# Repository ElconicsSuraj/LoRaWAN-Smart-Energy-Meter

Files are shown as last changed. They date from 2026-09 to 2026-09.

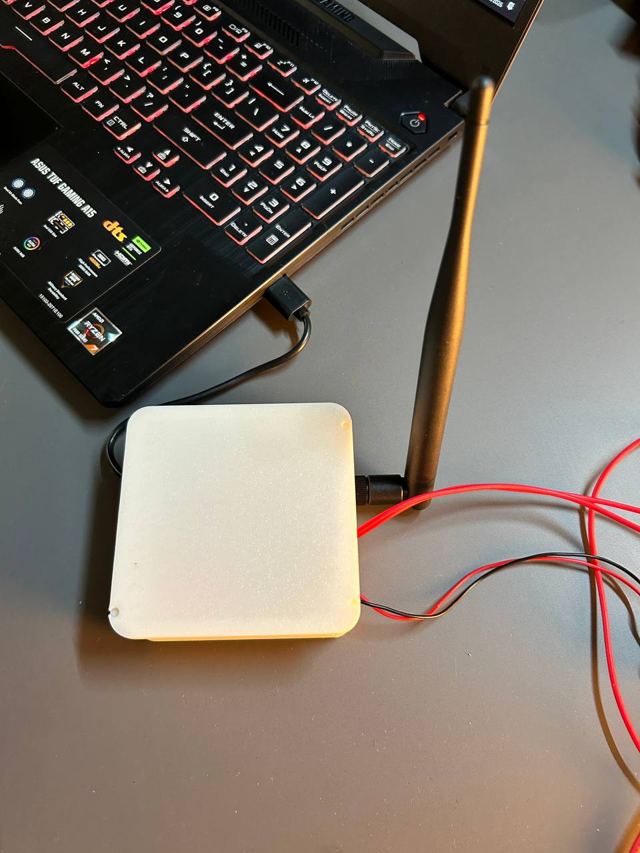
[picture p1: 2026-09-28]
Doc/images/photo_2026-09-28_18-33-33.jpg

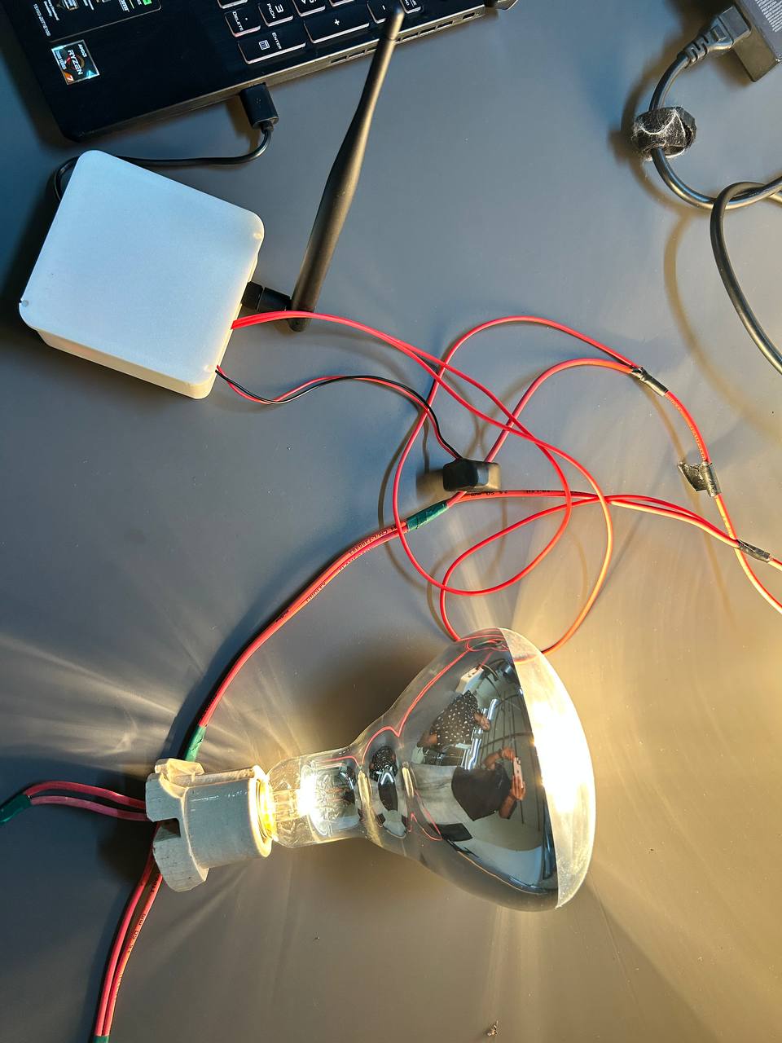
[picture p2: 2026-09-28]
Doc/images/photo_2026-09-28_18-33-32.jpg

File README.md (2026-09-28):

# LoRaWAN-Smart-Energy-Meter
A compact LoRaWAN-based energy monitoring system using the PZEM-004T V4 100A and Seeed Studio Wio-E5 Mini to remotely monitor voltage, current, power, energy consumption, power factor, and frequency.

The system uses the PZEM-004T V4 100A Energy Monitoring Module for electrical measurements and a Seeed Studio Wio-E5 Mini LoRaWAN board for long-range wireless communication.

It is suitable for applications such as industrial energy monitoring, smart buildings, agricultural equipment, commercial power monitoring, machine monitoring, and IoT-based energy management.

🚀 Features
⚡ Real-time voltage measurement
🔌 AC current measurement up to 100A
📊 Active power monitoring
🔋 Energy consumption measurement
📈 Power factor monitoring
📡 LoRaWAN long-range communication
🌐 Remote energy monitoring
🔧 Compact IoT node architecture
🔋 Suitable for low-power remote deployments
🏭 Suitable for industrial and commercial applications
🧩 Hardware Used
Component	Description
Seeed Studio Wio-E5 Mini	LoRaWAN communication controller
PZEM-004T V4 100A	AC voltage, current, power and energy measurement
100A CT	Non-invasive current measurement
Power Supply	Provides power to the monitoring node
Antenna	LoRa/LoRaWAN communication
Main Hardware

PZEM-004T V4 – 100A

Used to measure:

Voltage
Current
Active Power
Energy
Power Factor
Frequency

Wio-E5 Mini

Used as the wireless communication controller to transmit energy data over a LoRaWAN network.

🏗️ System Architecture
                 AC LOAD
                    │
                    │
             ┌──────▼──────┐
             │    100A CT  │
             └──────┬──────┘
                    │
                    ▼
          ┌───────────────────┐
          │   PZEM-004T V4    │
          │    Energy Meter   │
          │                   │
          │ V / A / W / kWh   │
          │ PF / Frequency    │
          └─────────┬─────────┘
                    │
                  UART
                    │
                    ▼
          ┌───────────────────┐
          │   Wio-E5 Mini     │
          │    LoRaWAN Node   │
          └─────────┬─────────┘
                    │
                 LoRaWAN
                    │
                    ▼
             ┌──────────────┐
             │ LoRaWAN      │
             │ Gateway      │
             └──────┬───────┘
                    │
                    ▼
             ┌──────────────┐
             │ LoRaWAN      │
             │ Network      │
             │ Server       │
             └──────┬───────┘
                    │
                    ▼
             ┌──────────────┐
             │ Dashboard /  │
             │ Cloud        │
             └──────────────┘
📡 LoRaWAN Communication

The Wio-E5 Mini communicates with a LoRaWAN gateway and transmits measured electrical parameters to the LoRaWAN network server.

Typical communication flow:

Energy Meter
     ↓
Wio-E5 Mini
     ↓
LoRaWAN
     ↓
Gateway
     ↓
LoRaWAN Network Server
     ↓
MQTT / API
     ↓
Dashboard

The device can be integrated with LoRaWAN network servers such as:

ChirpStack
The Things Stack
Other compatible LoRaWAN platforms
📊 Parameters

The device can transmit the following parameters:

Parameter	Unit
Voltage	V
Current	A
Active Power	W
Energy	kWh
Power Factor	PF
Frequency	Hz

Example payload:

{
  "voltage": 230.5,
  "current": 4.82,
  "power": 1087.4,
  "energy": 12.64,
  "power_factor": 0.98,
  "frequency": 50.0
}
🔄 Operating Flow
The PZEM-004T measures electrical parameters.
The Wio-E5 Mini communicates with the PZEM module.
Measurement data is processed by the firmware.
The data is formatted into a compact LoRaWAN payload.
The Wio-E5 Mini transmits the payload through LoRaWAN.
The LoRaWAN gateway receives the packet.
The network server processes the data.
Data can be forwarded to MQTT, database or dashboard applications.
🔌 PZEM-004T Interface

The PZEM-004T communicates with the controller using a serial interface.

Typical interface:

PZEM-004T          Wio-E5 Mini
-----------        -----------
TX      ----------> RX2
RX      <---------- TX3
GND     ----------- GND
VCC     ----------- Supply

Important: Verify the voltage levels and exact pin configuration of your PZEM-004T and Wio-E5 Mini hardware before connecting them.

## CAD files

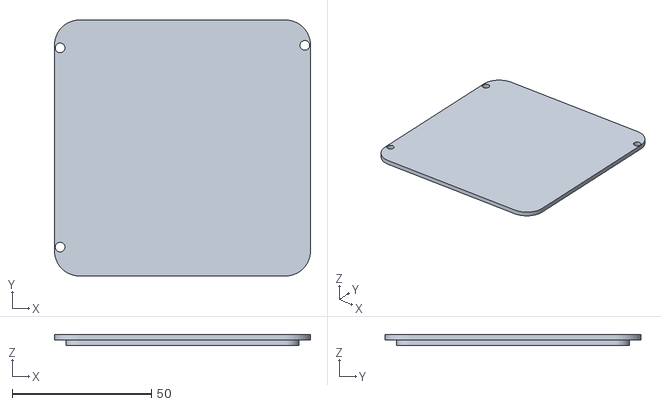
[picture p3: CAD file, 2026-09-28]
cad_file/main_box_lid.stl
92.0 x 92.0 x 4.00

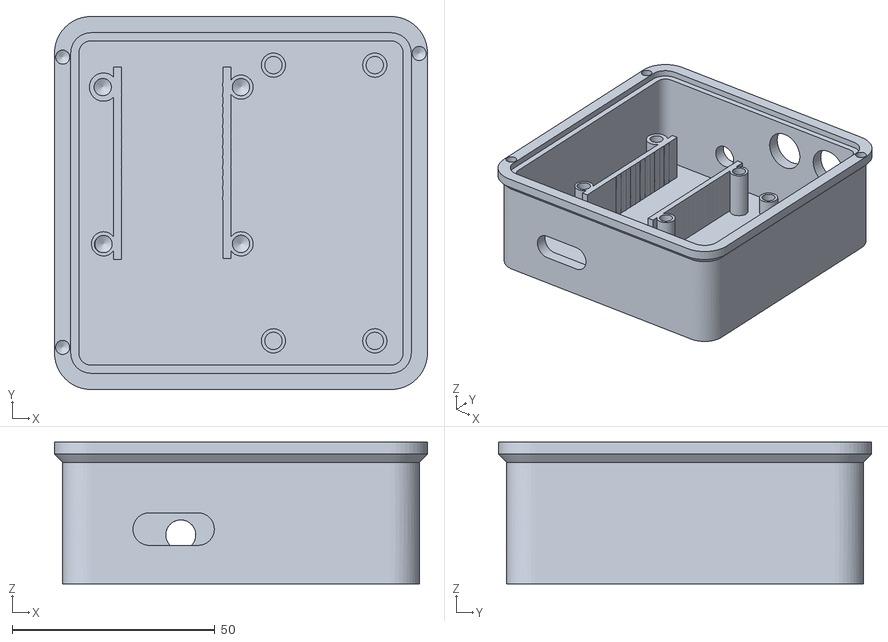
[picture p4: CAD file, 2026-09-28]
cad_file/main_box.stl
92.0 x 92.0 x 35.0

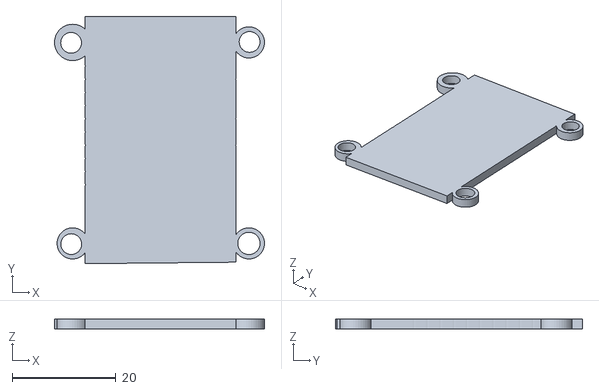
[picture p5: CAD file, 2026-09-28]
cad_file/mcu_cover.stl
40.4 x 47.6 x 2.00

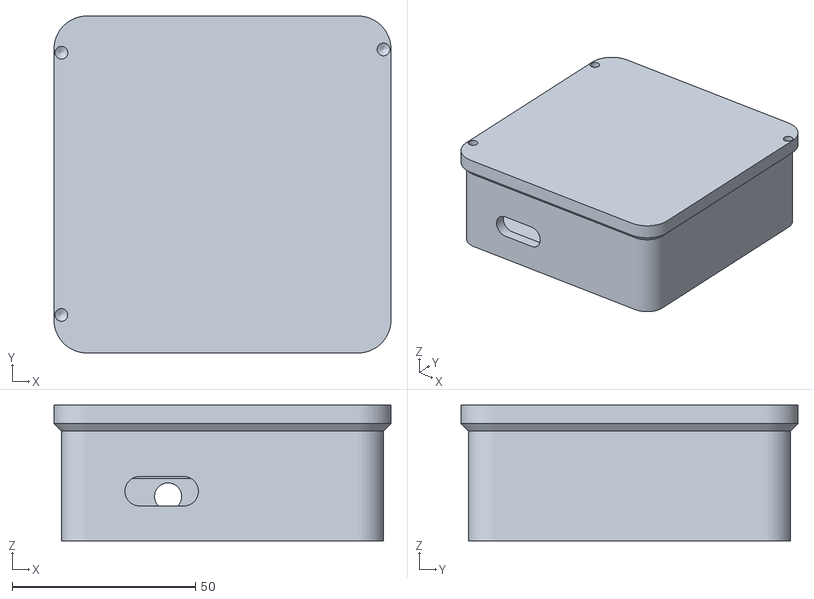
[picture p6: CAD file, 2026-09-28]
cad_file/energy_meter.stl
92.0 x 92.0 x 37.0

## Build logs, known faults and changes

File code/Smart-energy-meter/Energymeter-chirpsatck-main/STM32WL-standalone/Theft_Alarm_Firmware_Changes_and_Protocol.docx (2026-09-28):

Theft-Alarm LoRaWAN Node

Firmware Modification & Protocol Reference

Field | Value
Document Title | Theft-Alarm LoRaWAN Node – Firmware Modification & Protocol Reference
Base Project | STM32WL-standalone (LoRaWAN 1.0.3 stack, originally the ANTZ Systems Temperature/Humidity sensor build)
Target Hardware | Seeed Wio-E5 mini / LoRa-E5 mini (STM32WLE5), digital-output (DO) vibration sensor module
Purpose of This Build | Theft/tamper alarm – instant confirmed uplink on vibration detection, no periodic sensor reporting
Status | Working – validated end-to-end (interrupt → payload → confirmed uplink → ChirpStack decode)
Document Date | 2026-08-28

This document explains, in plain language, everything that was changed in this codebase to turn a temperature/humidity LoRaWAN reference project into a working vibration-based theft alarm — and defines the resulting uplink protocol so it can be handed to anyone building the backend/dashboard. Since this firmware started life as someone else's project, treat this as the map of “what's different from the original and why.”

# 1. What This Project Actually Is Now

The starting point was ST's official STM32WL standalone LoRaWAN example, already extended by a previous author (ANTZ Systems) into a temperature/humidity sensor node: it read a sensor every 30 seconds, stored readings into flash, and uplinked them periodically (message 0xA1), plus supported a few downlink commands for configuration and battery calibration.

That periodic-sensor design doesn't fit a theft alarm at all — an alarm needs to fire the instant something happens, not on the next scheduled tick, and there's no temperature/humidity sensor connected any more. So the changes below do three things: (1) make a vibration event uplink immediately and bypass all the queuing/scheduling built for periodic sensor data, (2) turn off the now-irrelevant periodic sensor path entirely, and (3) adapt the low-level board support (UART) to the physical board actually being used (a Wio-E5 mini) instead of the ST Nucleo board the original project assumed.

# 2. Hardware Setup

Item | Detail
Vibration sensor | LM393-comparator digital-output module (SW-420-style ball-switch board); onboard LED mirrors detection
Sensor output wiring | Sensor DO → MCU pin PB3 (board silkscreen label “A3”), interrupt line EXTI3
Final GPIO setting | GPIO_MODE_IT_RISING, GPIO_NOPULL (rising edge, no internal pull – see §3.1)
MCU / board | STM32WLE5 on Seeed Wio-E5 mini / LoRa-E5 mini – has a built-in USB-C→UART bridge on USART1 (PB6/PB7)
Debug/serial console | USART1, 115200 baud, 8N1, via the board's built-in USB-C port (no external TTL adapter needed)

One real debugging lesson worth keeping on record: partway through bring-up, the sensor's DO wire was physically plugged into a different pin than A3/PB3. That produced confusing symptoms — the sensor's own LED lit up on every tap (proving the sensor itself worked), but no uplink ever followed, while touching the bare A3 pin with a finger triggered rapid false uplinks from floating-pin noise. Once DO was correctly connected to A3, real taps produced clean, single, correct uplinks. If this ever seems to “stop working” again, re-check the physical DO→A3 connection first before suspecting the firmware.

# 3. Firmware Changes – What Was Done and Why

Five areas of the firmware were touched. Each is described below with the file(s) involved, the reasoning, and the actual code as it stands now.

## 3.1 Vibration Interrupt Configuration — gpio.c

The sensor's DO line drives the pin itself (it's a comparator output), so no internal pull resistor should fight it. After confirming (via live serial debug prints, not just multimeter guesses) that the sensor idles LOW and pulses HIGH on detection, the pin was set to trigger on the rising edge with no internal pull:

GPIO_InitStruct.Pin = VIBRATION_SENSOR_Pin; // PB3 / EXTI3

GPIO_InitStruct.Mode = GPIO_MODE_IT_RISING; // sensor pulses HIGH on detection

GPIO_InitStruct.Pull = GPIO_NOPULL; // DO is push-pull; no internal pull needed

(The original project had this configured as GPIO_MODE_IT_FALLING + GPIO_PULLUP, which assumes the opposite idle-HIGH/pulse-LOW behavior – correct for some sensor variants, but not this one.)

## 3.2 Disabling the Periodic Temperature/Humidity Uplink — application_logic.c

No temperature/humidity sensor is connected in this build, so the code that used to read it, store a sample to flash, and flag a periodic uplink (message 0xA1) was disabled. Rather than deleting it, it was wrapped in a compile-time #if 0 block inside run_application_logic() — nothing is lost, and it can be switched back on later just by removing the two marker lines:

else

{

/* Periodic temp/humidity message (0xA1) disabled for theft-alarm build.

* No temp/humidity sensor is connected; only vibration (0xA5) alerts are sent.

* Re-enable by removing the #if 0 / #endif below. */

#if 0

device_status = data_sampling;

turn_on_led(GREEN);

read_humidity_and_temperature(&write_sensor_data.temperature, &write_sensor_data.humidity);

write_sensor_data.epoch_time = SysTimeGet().Seconds;

uint8_t res = store_sample(&write_sensor_data);

if (1 == res)

{

write_sensor_data.sample_number += 1;

next_action.periodic_message_flag = 1;

}

turn_off_led(GREEN);

#endif

}

Effect: the SampleTimer still ticks every 30 seconds as before, but this function is now a no-op — no sensor read, no flash write, no 0xA1 uplink ever gets queued. Vibration alerts (0xA5) and the existing downlink-triggered replies (config report, battery calibration, erase samples) are untouched and continue to work, since they run through independent code paths.

## 3.3 Debug Instrumentation — lora_app.c

To make the vibration path observable during bring-up, a debug line was added exactly where the vibration packet is sent, printed over the serial console every time a vibration-triggered uplink is attempted:

if (1 == next_action.vibration_detected)

{

create_vibration_message_packet(AppData.Buffer);

AppData.BufferSize = VIBRATION_MESSAGE_SIZE; // 7 bytes: msg id, epoch time, vibration flag, battery

uint8_t res = flush_data_onto_cloud();

sprintf(debug_buffer, "Vibration TX attempt (res=%d): %02X%02X%02X%02X%02X%02X%02X\r\n",

res,

AppData.Buffer[0], AppData.Buffer[1], AppData.Buffer[2], AppData.Buffer[3],

AppData.Buffer[4], AppData.Buffer[5], AppData.Buffer[6]);

send_data_over_uart(debug_buffer);

}

res=1 means the LoRaWAN stack accepted the packet and began transmitting; the raw hex printed alongside it is the exact 7-byte payload that goes out over the air — handy for cross-checking against what ChirpStack receives.

## 3.4 UART Migration: USART2 → USART1

The original project (built for an ST Nucleo-WL55JC1 board) used USART2 on pins PA9/PA10 for its debug console, wired out to an external USB-to-serial adapter. The Wio-E5 mini / LoRa-E5 mini board used here instead has a USB-C port with a built-in USB→UART bridge wired in silicon to USART1 on PB6 (TX) / PB7 (RX) — a different physical peripheral, not just different pins. Since pin routing on this MCU isn't a free crossbar, six files needed to move from the USART2 configuration to a correct USART1 one:

File | Change
Drivers/Inc/main.h | USARTx_TX_Pin / USARTx_RX_Pin macros repointed to PB6 / PB7 (were PA9 / PA10)
Drivers/Inc/usart.h | Declares huart1 and MX_USART1_UART_Init() (was huart2 / MX_USART2_UART_Init())
Core/usart.c | Fully switched to the USART1 peripheral: correct clock source, GPIO port (GPIOB), alternate function (GPIO_AF7_USART1), DMA request (DMA_REQUEST_USART1_TX), and interrupt (USART1_IRQn)
Core/application_logic.c | send_data_over_uart() now initializes and transmits via huart1 instead of huart2
Core/stm32wlxx_it.c / stm32wlxx_it.h | Interrupt handler renamed USART2_IRQHandler → USART1_IRQHandler, wired to huart1
Core/usart_if.c | Updated for naming consistency only — this file is dead code (never called at runtime), kept just so the project still compiles cleanly

Result: plugging the Wio-E5 mini into a computer over its USB-C port now gives a working serial console directly, at 115200-8-N-1, with no external TTL adapter required.

## 3.5 Vibration Payload Redesign — protocol.h / protocol.c / lora_app.c

The vibration message originally reused the 13-byte periodic-message layout and pulled its “epoch time” and “sample number” fields from the same flash sample-reader used by the (now-disabled) temperature/humidity path. In practice that meant a vibration alert usually carried epoch time = 0 and sample number = 0, because no periodic sample happened to be pending in flash at that instant — the timestamp was borrowed data, not a real capture of when the vibration actually happened.

Since knowing exactly when a theft alert fired matters, this was replaced with a compact, purpose-built 7-byte format that stamps the real time at the moment of the event, using the LoRaWAN stack's own system clock (SysTimeGet()) directly — no dependency on the flash sample queue at all:

// protocol.h

#define VIBRATION_MESSAGE_SIZE 7

// protocol.c

void create_vibration_message_packet(uint8_t *buf)

{

memset(buf, 0, LORAWAN_APP_DATA_BUFFER_MAX_SIZE);

uint32_t epoch_now = SysTimeGet().Seconds;

buf[0] = vibration_message; // 0xA5

/* bytes 1-4: live epoch time at the moment of this vibration event */

buf[1] = (epoch_now & 0xFF000000) >> 24;

buf[2] = (epoch_now & 0x00FF0000) >> 16;

buf[3] = (epoch_now & 0x0000FF00) >> 8;

buf[4] = epoch_now & 0xFF;

/* byte 5: vibration flag (1 = vibration detected) */

buf[5] = 0x01;

/* byte 6: battery percentage */

buf[6] = get_battery_percentage();

}

lora_app.c's send path was updated to match — AppData.BufferSize now uses the new VIBRATION_MESSAGE_SIZE (7) constant instead of the old 13-byte PERIODIC_MESSAGE_SIZE, and the debug print (§3.3) was trimmed to print 7 bytes instead of 13.

## 3.6 Summary – All Files Touched

File | What Changed
Core/gpio.c | Vibration pin (PB3/EXTI3): rising edge, no internal pull
Core/application_logic.c | Periodic temp/humidity sampling disabled (#if 0); UART calls repointed to huart1
LoRaWAN/App/lora_app.c | Vibration TX debug print added; buffer size switched to the new 7-byte format
Drivers/Inc/protocol.h | Added VIBRATION_MESSAGE_SIZE (7)
Core/protocol.c | create_vibration_message_packet() rewritten: live epoch timestamp, no flash dependency
Drivers/Inc/main.h | UART pin macros repointed to PB6/PB7
Drivers/Inc/usart.h | Declares huart1 / MX_USART1_UART_Init()
Core/usart.c | Switched from USART2 to USART1 peripheral (clock, GPIO AF, DMA, IRQ)
Core/stm32wlxx_it.c / .h | USART interrupt handler renamed to USART1_IRQHandler
Core/usart_if.c | Renamed for consistency (unused/dead code, doesn't affect runtime)

Not a git repository, so no formal diff/patch exists — the snippets above are the authoritative record of what changed.

# 4. Uplink/Downlink Protocol – Current State

This section documents the protocol as it actually behaves in this build, extending the original project's protocol spec with the new vibration message and flagging what's now inactive.

## 4.1 Vibration Alert — 0xA5 (new, primary message for this project)

Size: 7 bytes

Trigger: Immediately on the rising edge of the vibration sensor's DO output (EXTI3 interrupt) — not on a timer, and not gated by link-check status.

Confirmation: Sent as a confirmed LoRaWAN uplink (ACK requested from the network server).

Byte | Field | Type | Encoding
0 | Message ID | uint8 | 0xA5 (vibration_message)
1–4 | Epoch Time | uint32 BE | Unix timestamp (seconds), captured live via SysTimeGet() at the moment of the event
5 | Vibration Flag | uint8 | 0x01 = vibration detected
6 | Battery | uint8 | 0–100 (%)

### Example

Hex payload: A5 6A9132C4 01 64

Field | Hex | Decoded
Message ID | A5 | 0xA5 (Vibration Alert)
Epoch Time | 6A9132C4 | 1787900612 → 2026-08-28 12:33:32 IST
Vibration Flag | 01 | Vibration detected
Battery | 64 | 100%

## 4.2 Messages Carried Over From the Original Project

These still exist in the code and remain functional, but their relevance has changed now that there's no temperature/humidity sensor in this build:

Msg | Name | Size | Status in This Build
0xA1 | Periodic Sensor Data | 13 bytes | Disabled — code path is compiled out (§3.2); no longer sent
0xA2 | Device Configuration Report | 8 bytes | Still functional (responds to 0xB1/0xB2), but sample_interval reported is now meaningless since sampling is off
0xA3 | Battery Calibration ACK | 2 bytes | Still functional and useful — unrelated to sensor sampling
0xA4 | Erase Samples ACK | 2 bytes | Still functional, though the flash sample buffer it clears is no longer being written to
0xB1 | Update Sampling Interval (downlink) | 3 bytes | Still accepted, but has no visible effect since sampling is disabled
0xB2 | Fetch Device Configuration (downlink) | 1 byte | Still functional
0xB3 | Battery Calibration (downlink) | 2 bytes | Still functional
0xB4 | Erase Pending Samples (downlink) | 1 byte | Still functional

Recommendation: if 0xA1/0xB1 aren't going to be revisited, it's worth deciding whether to keep them wired up (no harm, just unused) or strip them later for a cleaner build — not urgent either way.

## 4.3 Application-Layer Clock Synchronization (Port 202)

Inherited from the original project: a ClockSyncTimer fires 10 seconds after boot, then every 8 hours, and runs the standard LoRaWAN Application Layer Clock Synchronization package (AppTimeReq/AppTimeAns) on dedicated port 202. This is how the device's epoch clock (used in the 0xA5 payload) gets corrected against the network's time — not GPS, not a manually-set RTC.

Caveat worth tracking: this correction only lands if the AppTimeAns downlink is actually received, which depends on the same RF link used for confirmed-uplink ACKs. A weak link (see §5) can cause this sync to silently fail, leaving the device coasting on a stale correction — which is consistent with a small (~18–19 second) constant timestamp offset observed during testing.

# 5. Known Issue – RF Link Margin

During testing, ChirpStack's LinkCheckAns (the network server's answer to the device's automatic link-check, triggered after a failed confirmed-uplink ACK) reported a demodulation margin of 0 dB. That means the uplink was received right at the edge of decodability — no headroom. This is consistent with the repeated “No ACK Received. Starting link check recovery.” and “Message Send Fail” lines seen in the debug log: the device is transmitting correctly, ChirpStack is receiving the uplinks and does attempt the ACK, but the return path (gateway → device) is marginal enough that the device often doesn't hear it.

This isn't a firmware defect — it's a physical-layer/range issue. It's worth keeping in mind because it affects two things beyond just “noisy logs”: confirmed-uplink reliability, and (per §4.3) the reliability of the periodic clock re-sync. Options if it needs to be tightened up: improve antenna placement/line-of-sight to the gateway, or force a lower data rate (more spreading factor = more sensitivity margin, at the cost of airtime).

# 6. Network-Side: ChirpStack Payload Decoder

On the ChirpStack side (Device Profile → Codec tab → Custom JavaScript codec), a decodeUplink() function was added so the dashboard/API sees a clean decoded object instead of raw hex on every uplink:

function decodeUplink(input) {

var bytes = input.bytes;

var msgId = bytes[0];

function toEpoch(b1, b2, b3, b4) {

return ((b1 << 24) | (b2 << 16) | (b3 << 8) | b4) >>> 0;

}

function toIST(epochSeconds) {

var utcMs = epochSeconds * 1000;

var istMs = utcMs + (5 * 60 + 30) * 60 * 1000; // UTC+5:30

var d = new Date(istMs);

var pad = function (n) { return (n < 10 ? "0" : "") + n; };

return d.getUTCFullYear() + "-" + pad(d.getUTCMonth() + 1) + "-" + pad(d.getUTCDate()) +

" " + pad(d.getUTCHours()) + ":" + pad(d.getUTCMinutes()) + ":" + pad(d.getUTCSeconds()) + " IST";

}

if (msgId === 0xA5 && bytes.length === 7) {

var epoch = toEpoch(bytes[1], bytes[2], bytes[3], bytes[4]);

return {

data: {

message_type: "Vibration Alert",

alert: bytes[5] === 1 ? "Vibration detected!" : "No vibration",

event_time_ist: toIST(epoch),

event_time_utc: new Date(epoch * 1000).toISOString(),

battery_percent: bytes[6]

}

};

}

if (msgId === 0xA2 && bytes.length === 8) {

var batteryCounter = toEpoch(bytes[1], bytes[2], bytes[3], bytes[4]);

return {

data: {

message_type: "Device Config Report",

battery_counter: batteryCounter,

sample_interval_sec: (bytes[5] << 8) | bytes[6],

battery_percent: bytes[7]

}

};

}

if (msgId === 0xA3 && bytes.length === 2) {

return { data: { message_type: "Battery Calibration ACK", battery_percent: bytes[1] } };

}

if (msgId === 0xA4 && bytes.length === 2) {

return { data: { message_type: "Erase Samples ACK", battery_percent: bytes[1] } };

}

return {

data: {

message_type: "Unknown",

raw_hex: bytes.map(function (b) { return ("0" + b.toString(16)).slice(-2); }).join("").toUpperCase()

}

};

}

For a vibration alert, the decoded object looks like this (shown in ChirpStack's event detail view, and delivered the same way to any app/dashboard reading via the API or MQTT integration):

{

"message_type": "Vibration Alert",

"alert": "Vibration detected!",

"event_time_ist": "2026-08-28 12:33:32 IST",

"event_time_utc": "2026-08-28T07:03:12.000Z",

"battery_percent": 100

}

Note: this codec lives only on the ChirpStack server — it's not part of the firmware, and changing it requires no reflash, just editing it in the Device Profile's Codec tab.

# 7. Quick Reference

## 7.1 Pin Map

Signal | Pin | Notes
Vibration sensor DO | PB3 (silkscreen “A3”) | EXTI3, rising edge, no pull
Debug UART TX | PB6 | USART1, via built-in USB-C bridge
Debug UART RX | PB7 | USART1, via built-in USB-C bridge

## 7.2 Message ID Map

ID | Direction | Name | Active in This Build?
0xA1 | Uplink | Periodic Sensor Data | No – disabled
0xA2 | Uplink | Device Configuration Report | Yes
0xA3 | Uplink | Battery Calibration ACK | Yes
0xA4 | Uplink | Erase Samples ACK | Yes
0xA5 | Uplink | Vibration Alert | Yes – primary message
0xB1 | Downlink | Update Sampling Interval | Accepted, no effect
0xB2 | Downlink | Fetch Device Configuration | Yes
0xB3 | Downlink | Battery Calibration | Yes
0xB4 | Downlink | Erase Pending Samples | Yes

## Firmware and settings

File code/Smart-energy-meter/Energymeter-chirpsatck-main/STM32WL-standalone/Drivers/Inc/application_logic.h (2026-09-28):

/*
 * application_logic.h
 *
 *  Created on: Aug 21, 2025
 *      Author: Amogh MP
 */

#ifndef INC_APPLICATION_LOGIC_H_
#define INC_APPLICATION_LOGIC_H_


#include <stdint.h>
#include "eeprom.h"
#include "gpio.h"
#include "temp_humidity_sensor.h"
#include "rtc.h"


#define LORAWAN_MAX_RETRY_JOIN_ATTEMPTS   				14 // approx 3 hours considering the exponential backoff


#define DEFAULT_UPLOAD_INTERVAL_IN_SECONDS				10


#define DEFAULT_MINIMUM_SAMPLING_INTERVAL_IN_SEC		30
#define DEFAULT_MAXIMUM_SAMPLING_INTERVAL_IN_SEC		65535


#define LINK_CHECK_RETRY_INTERVAL_MS				(2 * 60 * 1000)  // 2 minutes
#define LINK_CHECK_MAX_RETRY_ATTEMPTS				15  // ~30 min at 2-min intervals

#define FLASH_FULL_THRESHOLD						(MAX_SAMPLES - SAMPLES_PER_PAGE)  // 576 samples (1 page headroom)

#define VIBRATION_COOLDOWN_MS					(30 * 1000)  // 30 seconds between vibration alerts
#define VIBRATION_WINDOW_MS						200          // 200 ms pulse counting window
#define VIBRATION_PULSE_THRESHOLD				1            // Immediate trigger on falling edge event

#define JANUARY_1_2025_EPOCH							1735689600
#define JANUARY_1_2050_EPOCH							2524608001





extern volatile uint8_t sw_pressed;

extern uint8_t can_send_temperature_alerts;
extern uint8_t can_send_humidity_alerts;


extern char debug_buffer[256];


extern uint8_t downlink_data_buffer[256];
extern uint8_t downlink_processing_buffer[256];

extern uint32_t number_of_cycles_to_send_data;
extern uint32_t number_of_cycles_to_sample_sensor;
extern uint32_t data_sending_counter;
extern uint32_t sensor_sampling_counter;
extern uint32_t device_connection_retry_counter;




typedef enum
{
	unknown = 0,

	joining,
	join_successful,
	join_fail,

	time_sync_in_progress,
	time_sync_successfull,
	time_sync_fail,

	link_check_in_progress,
	link_check_successfull,
	link_check_fail,

	data_sampling,
	payload_uplinks

}device_status_e;

extern device_status_e device_status;


void send_data_over_uart(char* str);
uint8_t get_battery_percentage(void);
void process_downlink_data(uint8_t* buffer, uint8_t payload_size);
void check_if_user_switch_pressed(void);
void run_application_logic(void);


#endif /* INC_APPLICATION_LOGIC_H_ */

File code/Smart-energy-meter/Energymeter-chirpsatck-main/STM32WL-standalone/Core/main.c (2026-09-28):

#include "main.h"
#include "app_lorawan.h"
#include "stm32wlxx_hal_spi.h"
#include "lora_app.h"
#include "sys_app.h"
#include "stm32_seq.h"


#include "gpio.h"
#include "usart.h"
#include "eeprom.h"
#include "application_logic.h"
#include "pzem004t.h"


IWDG_HandleTypeDef hiwdg; // TODO: AMP 29/08/2025



void SystemClock_Config(void);
void MX_GPIO_Init(void);
void IWDG_Init(void); // TODO: AMP 29/08/2025
void MX_SPI1_Init(void);
void MX_TIM2_Init(void);

SPI_HandleTypeDef hspi1;

TIM_HandleTypeDef htim2;


void reset_cause_get(void)
{
    uint32_t reset_cause = RCC->CSR;

	if (reset_cause & RCC_CSR_IWDGRSTF)
	{
		sprintf(debug_buffer, "IWDG Reset (Independent Watchdog timeout)\r\n");
	}
	else if (reset_cause & RCC_CSR_WWDGRSTF)
	{
		sprintf(debug_buffer, "WWDG Reset (Window Watchdog)\r\n");
	}
	else if (reset_cause & RCC_CSR_SFTRSTF)
	{
		sprintf(debug_buffer, "Software Reset\r\n");
	}
	else if (reset_cause & RCC_CSR_PINRSTF)
	{
		sprintf(debug_buffer, "NRST Pin Reset\r\n");
	}
	else if (reset_cause & RCC_CSR_BORRSTF)
	{
		sprintf(debug_buffer, "Brownout Reset\r\n");
	}
	else
	{
		sprintf(debug_buffer, "Unknown or No Specific Reset Flag\r\n");
	}

	send_data_over_uart(debug_buffer);

	// Clear all reset flags by setting RMVF (bit 23)
	RCC->CSR |= RCC_CSR_RMVF;

}



int main(void)
{

	HAL_Init();
	SystemClock_Config();

	/* Initialize USART1 (debug UART on PB6/PB7) once - stays open permanently */
	MX_USART1_UART_Init();

	reset_cause_get();

	IWDG_Init();

	HAL_IWDG_Refresh(&hiwdg);
	memset(&write_sensor_data, 0, sizeof(write_sensor_data));

	HAL_IWDG_Refresh(&hiwdg);
	init_sample_storage();

	sprintf(debug_buffer, "device_config.new_program: %02X, device_config.sample_interval: %d, "
			"device_config.upload_interval: %d, device_config.write_counter: %d, device_config.read_counter: %d, "
			"device_config.battery_counter: %d\r\n",
			device_config.new_program, device_config.sample_interval, device_config.upload_interval,
			device_config.write_counter, device_config.read_counter, device_config.battery_counter);
	send_data_over_uart(debug_buffer);

	HAL_IWDG_Refresh(&hiwdg);
	MX_GPIO_Init();

	/* Initialize USART2 for PZEM-004T (PA2=TX2, PA3=RX2, 9600 baud, 8N1) */
	MX_USART2_UART_Init();
	send_data_over_uart("PZEM USART2 Init OK\r\n");

	HAL_IWDG_Refresh(&hiwdg);
	SystemApp_Init();

	HAL_IWDG_Refresh(&hiwdg);
	turn_on_led(RED);
	HAL_Delay(1000);
	HAL_IWDG_Refresh(&hiwdg);
	turn_off_led(RED);

	HAL_IWDG_Refresh(&hiwdg);
	LoRaWAN_Init();
	send_data_over_uart("LoRaWAN Init OK\r\n");


	while (1)
	{
		HAL_IWDG_Refresh(&hiwdg);
		MX_LoRaWAN_Process();
	}
}


void SystemClock_Config(void)
{
	RCC_OscInitTypeDef RCC_OscInitStruct = {0};
	RCC_ClkInitTypeDef RCC_ClkInitStruct = {0};

	/** Configure LSE Drive Capability
	 */
	HAL_PWR_EnableBkUpAccess();
	__HAL_RCC_LSEDRIVE_CONFIG(RCC_LSEDRIVE_LOW);
	/** Configure the main internal regulator output voltage
	 */
	__HAL_PWR_VOLTAGESCALING_CONFIG(PWR_REGULATOR_VOLTAGE_SCALE1);
	/** Initializes the CPU, AHB and APB busses clocks
	 */
	RCC_OscInitStruct.OscillatorType = RCC_OSCILLATORTYPE_LSI|RCC_OSCILLATORTYPE_LSE|RCC_OSCILLATORTYPE_MSI;
	RCC_OscInitStruct.LSEState = RCC_LSE_ON;
	RCC_OscInitStruct.MSIState = RCC_MSI_ON;
	RCC_OscInitStruct.MSICalibrationValue = RCC_MSICALIBRATION_DEFAULT;
	RCC_OscInitStruct.MSIClockRange = RCC_MSIRANGE_11;
	RCC_OscInitStruct.LSIDiv = RCC_LSI_DIV1; // TODO: AMP 08/09/2025
	RCC_OscInitStruct.LSIState = RCC_LSI_ON; // TODO: AMP 08/09/2025
	RCC_OscInitStruct.PLL.PLLState = RCC_PLL_NONE;
	if (HAL_RCC_OscConfig(&RCC_OscInitStruct) != HAL_OK)
	{
		Error_Handler();
	}
	/** Configure the SYSCLKSource, HCLK, PCLK1 and PCLK2 clocks dividers
	 */
	RCC_ClkInitStruct.ClockType = RCC_CLOCKTYPE_HCLK3|RCC_CLOCKTYPE_HCLK
			|RCC_CLOCKTYPE_SYSCLK|RCC_CLOCKTYPE_PCLK1
			|RCC_CLOCKTYPE_PCLK2;
	RCC_ClkInitStruct.SYSCLKSource = RCC_SYSCLKSOURCE_MSI;
	RCC_ClkInitStruct.AHBCLKDivider = RCC_SYSCLK_DIV1;
	RCC_ClkInitStruct.APB1CLKDivider = RCC_HCLK_DIV1;
	RCC_ClkInitStruct.APB2CLKDivider = RCC_HCLK_DIV1;
	RCC_ClkInitStruct.AHBCLK3Divider = RCC_SYSCLK_DIV1;

	if (HAL_RCC_ClockConfig(&RCC_ClkInitStruct, FLASH_LATENCY_2) != HAL_OK)
	{
		Error_Handler();
	}
}


void IWDG_Init(void) // TODO: AMP 29/08/2025
{
    hiwdg.Instance = IWDG;
    hiwdg.Init.Prescaler = IWDG_PRESCALER_256;
    hiwdg.Init.Reload = 4095;
    hiwdg.Init.Window = 4095;

    if (HAL_IWDG_Init(&hiwdg) != HAL_OK)
    {
        Error_Handler(); // Call error handler if initialization fails
    }
}


/**
  * @brief SPI1 Initialization Function
  * @param None
  * @retval None
  */
void MX_SPI1_Init(void)
{
//  /* SPI1 parameter configuration*/
//  hspi1.Instance = SPI1;
//  hspi1.Init.Mode = SPI_MODE_MASTER;
//  hspi1.Init.Direction = SPI_DIRECTION_2LINES;
//  hspi1.Init.DataSize = SPI_DATASIZE_8BIT;
//  hspi1.Init.CLKPolarity = SPI_POLARITY_HIGH;
//  hspi1.Init.CLKPhase = SPI_PHASE_1EDGE;
//  hspi1.Init.NSS = SPI_NSS_SOFT;
//  hspi1.Init.BaudRatePrescaler = SPI_BAUDRATEPRESCALER_8;
//  hspi1.Init.FirstBit = SPI_FIRSTBIT_MSB;
//  hspi1.Init.TIMode = SPI_TIMODE_DISABLE;
//  hspi1.Init.CRCCalculation = SPI_CRCCALCULATION_DISABLE;
//  hspi1.Init.CRCPolynomial = 7;
//  hspi1.Init.CRCLength = SPI_CRC_LENGTH_DATASIZE;
//  hspi1.Init.NSSPMode = SPI_NSS_PULSE_ENABLE;
//  if (HAL_SPI_Init(&hspi1) != HAL_OK)
//  {
//    Error_Handler();
//  }
}

/**
  * @brief GPIO Initialization Function
  * @param None
  * @retval None
  */
//void MX_GPIO_Init(void)
//{
//  /* GPIO Ports Clock Enable */
//  __HAL_RCC_GPIOC_CLK_ENABLE();
//  __HAL_RCC_GPIOA_CLK_ENABLE();
//  __HAL_RCC_GPIOB_CLK_ENABLE();
//
//	GPIO_InitTypeDef CS_init;
//	CS_init.Mode = GPIO_MODE_OUTPUT_PP;
//	CS_init.Pin = GPIO_PIN_2;
//	CS_init.Speed = GPIO_SPEED_FREQ_VERY_HIGH;
//	HAL_GPIO_Init(GPIOC, &CS_init);
//
//	GPIO_InitTypeDef RST_init;
//	RST_init.Mode = GPIO_MODE_OUTPUT_PP;
//	RST_init.Pin = GPIO_PIN_2;
//	RST_init.Speed = GPIO_SPEED_FREQ_VERY_HIGH;
//	HAL_GPIO_Init(GPIOB, &RST_init);
//
//	GPIO_InitTypeDef DC_init;
//	DC_init.Mode = GPIO_MODE_OUTPUT_PP;
//	DC_init.Pin = GPIO_PIN_10;
//	DC_init.Speed = GPIO_SPEED_FREQ_VERY_HIGH;
//	HAL_GPIO_Init(GPIOB, &DC_init);
//}


void MX_TIM2_Init(void)
{
  __HAL_RCC_TIM2_CLK_ENABLE();  // Enable clock for TIM2
  TIM_ClockConfigTypeDef sClockSourceConfig = {0};
  TIM_MasterConfigTypeDef sMasterConfig = {0};

  htim2.Instance = TIM2;
  htim2.Init.Prescaler = 48-1;
  htim2.Init.CounterMode = TIM_COUNTERMODE_UP;
  htim2.Init.Period = 0xFFFFFFFF;
  htim2.Init.ClockDivision = TIM_CLOCKDIVISION_DIV1;
  htim2.Init.AutoReloadPreload = TIM_AUTORELOAD_PRELOAD_DISABLE;
  if (HAL_TIM_Base_Init(&htim2) != HAL_OK)
  {
    Error_Handler();
  }

  sClockSourceConfig.ClockSource = TIM_CLOCKSOURCE_INTERNAL;
  if (HAL_TIM_ConfigClockSource(&htim2, &sClockSourceConfig) != HAL_OK)
  {
    Error_Handler();
  }

  sMasterConfig.MasterOutputTrigger = TIM_TRGO_RESET;
  sMasterConfig.MasterSlaveMode = TIM_MASTERSLAVEMODE_DISABLE;
  if (HAL_TIMEx_MasterConfigSynchronization(&htim2, &sMasterConfig) != HAL_OK)
  {
    Error_Handler();
  }
}



void Error_Handler(void)
{
	/* User can add his own implementation to report the HAL error return state */
	__disable_irq();
	while (1)
	{
	}
}

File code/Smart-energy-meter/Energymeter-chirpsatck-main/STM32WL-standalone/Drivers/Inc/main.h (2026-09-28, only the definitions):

#define RTC_N_PREDIV_S 10
#define RTC_PREDIV_S ((1<<RTC_N_PREDIV_S)-1)
#define RTC_PREDIV_A ((1<<(15-RTC_N_PREDIV_S))-1)
#define LED1_Pin GPIO_PIN_15
#define LED1_GPIO_Port GPIOB
#define LED2_Pin GPIO_PIN_9
#define LED2_GPIO_Port GPIOB
#define PROB3_Pin GPIO_PIN_14
#define PROB3_GPIO_Port GPIOB
#define RF_CTRL3_Pin GPIO_PIN_3
#define RF_CTRL3_GPIO_Port GPIOC
#define BUT1_Pin GPIO_PIN_0
#define BUT1_GPIO_Port GPIOA
#define BUT1_EXTI_IRQn EXTI0_IRQn
#define PROB2_Pin GPIO_PIN_13
#define PROB2_GPIO_Port GPIOB
#define RF_CTRL2_Pin GPIO_PIN_5
#define RF_CTRL2_GPIO_Port GPIOC
#define PROB1_Pin GPIO_PIN_12
#define PROB1_GPIO_Port GPIOB
#define RF_CTRL1_Pin GPIO_PIN_4
#define RF_CTRL1_GPIO_Port GPIOC
#define BUT3_Pin GPIO_PIN_6
#define BUT3_GPIO_Port GPIOC
#define BUT2_Pin GPIO_PIN_1
#define BUT2_GPIO_Port GPIOA
#define BUT2_EXTI_IRQn EXTI1_IRQn
#define LED3_Pin GPIO_PIN_11
#define LED3_GPIO_Port GPIOB
#define USARTx_RX_Pin GPIO_PIN_7
#define USARTx_RX_GPIO_Port GPIOB
#define USARTx_TX_Pin GPIO_PIN_6
#define USARTx_TX_GPIO_Port GPIOB
#define PROB4_Pin GPIO_PIN_10
#define PROB4_GPIO_Port GPIOB
#define RED_LED_Pin GPIO_PIN_10
#define RED_LED_GPIO_Port GPIOA
#define GREEN_LED_Pin GPIO_PIN_11
#define GREEN_LED_GPIO_Port GPIOA
#define BLUE_LED_Pin GPIO_PIN_12
#define BLUE_LED_GPIO_Port GPIOA
#define RF_Supply_SW_Pin GPIO_PIN_5
#define RF_Supply_SW_GPIO_Port GPIOA
#define CTRL1_PIN_Pin GPIO_PIN_2
#define CTRL1_PIN_GPIO_Port GPIOB
#define VIBRATION_SENSOR_Pin GPIO_PIN_3
#define VIBRATION_SENSOR_GPIO_Port GPIOB
#define VIBRATION_SENSOR_EXTI_IRQn EXTI3_IRQn
#define DS18B20_PORT GPIOA
#define DS18B20_PIN GPIO_PIN_8
#define USER_SW_Pin GPIO_PIN_13
#define USER_SW_GPIO_Port GPIOC
#define USER_SW_EXTI_IRQn EXTI15_10_IRQn

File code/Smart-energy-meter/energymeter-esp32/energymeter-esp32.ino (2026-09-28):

#define PZEM_RX_PIN 16
#define PZEM_TX_PIN 17
#define PZEM_ADDR   0x01   // use 0xF8 if address is unknown (single module only)

uint16_t crc16(const uint8_t *buf, uint8_t len) {
  uint16_t crc = 0xFFFF;
  for (uint8_t i = 0; i < len; i++) {
    crc ^= buf[i];
    for (uint8_t b = 0; b < 8; b++)
      crc = (crc & 1) ? (crc >> 1) ^ 0xA001 : crc >> 1;
  }
  return crc;
}

bool readPZEM(float &v, float &i, float &p, float &e, float &f, float &pf, uint16_t &alarm) {
  uint8_t req[8] = {PZEM_ADDR, 0x04, 0x00, 0x00, 0x00, 0x0A, 0, 0};
  uint16_t c = crc16(req, 6);
  req[6] = c & 0xFF; req[7] = c >> 8;

  while (Serial2.available()) Serial2.read();      // flush old bytes
  Serial2.write(req, 8);

  uint8_t resp[25];
  if (Serial2.readBytes(resp, 25) != 25) return false;          // timeout
  if (resp[0] != PZEM_ADDR || resp[1] != 0x04 || resp[2] != 20) return false;
  c = crc16(resp, 23);
  if (resp[23] != (c & 0xFF) || resp[24] != (c >> 8)) return false;  // CRC fail

  auto reg = [&](int n) -> uint16_t { return (resp[3 + 2*n] << 8) | resp[4 + 2*n]; };

  v     = reg(0) * 0.1f;
  i     = (((uint32_t)reg(2) << 16) | reg(1)) * 0.001f;
  p     = (((uint32_t)reg(4) << 16) | reg(3)) * 0.1f;
  e     = (((uint32_t)reg(6) << 16) | reg(5));        // Wh
  f     = reg(7) * 0.1f;
  pf    = reg(8) * 0.01f;
  alarm = reg(9);
  return true;
}

void setup() {
  Serial.begin(115200);
  Serial2.begin(9600, SERIAL_8N1, PZEM_RX_PIN, PZEM_TX_PIN);
  Serial2.setTimeout(500);
}

void loop() {
  float v, i, p, e, f, pf; uint16_t alarm;
  if (readPZEM(v, i, p, e, f, pf, alarm)) {
    Serial.printf("V: %.1f V | I: %.3f A | P: %.1f W | E: %.0f Wh | F: %.1f Hz | PF: %.2f | Alarm: %s\n",
                  v, i, p, e, f, pf, alarm ? "YES" : "no");
  } else {
    Serial.println("PZEM read failed");
  }
  delay(2000);
}

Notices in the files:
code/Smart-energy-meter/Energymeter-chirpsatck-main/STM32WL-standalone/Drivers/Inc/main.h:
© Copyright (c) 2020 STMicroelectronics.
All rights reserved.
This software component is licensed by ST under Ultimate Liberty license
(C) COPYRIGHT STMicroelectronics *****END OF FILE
